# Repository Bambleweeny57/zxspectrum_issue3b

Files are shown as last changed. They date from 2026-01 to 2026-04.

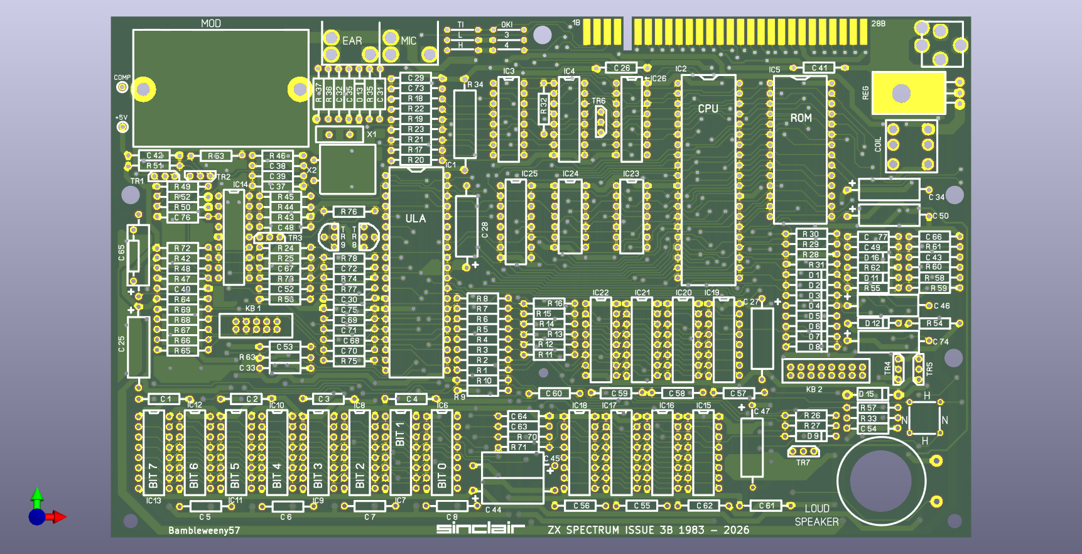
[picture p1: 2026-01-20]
images/issue3b.png

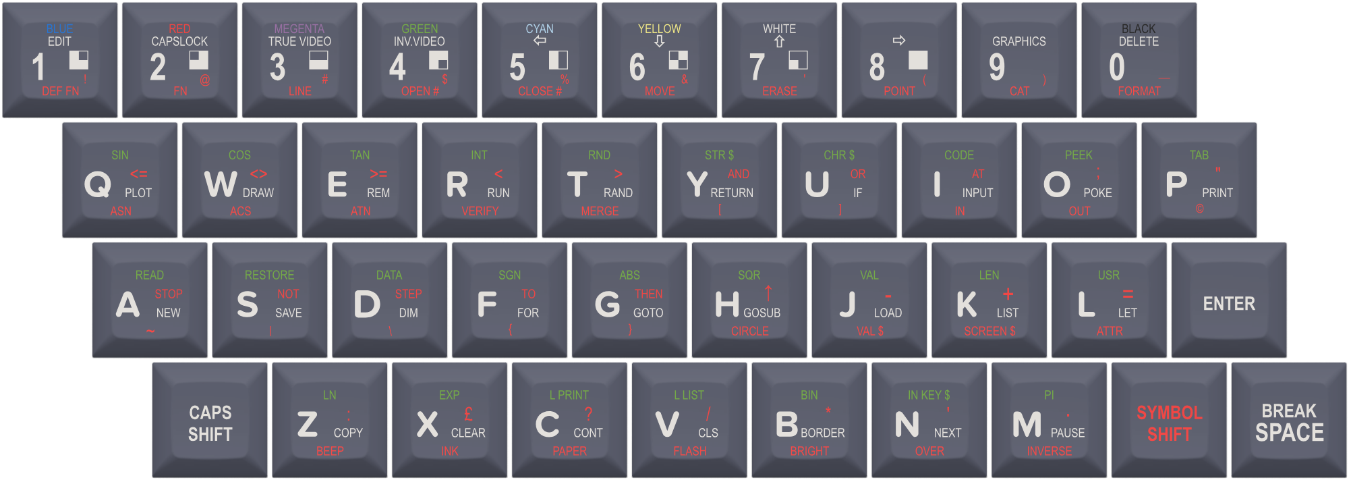
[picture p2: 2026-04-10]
images/ZXSpectrum-Keycaps.png

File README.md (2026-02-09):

# **ZX Spectrum Issue 3B — KiCad Reconstruction**

A faithful KiCad recreation of the **Sinclair ZX Spectrum Issue 3B motherboard**, reconstructed from original Gerber data and fully validated through multiple successful builds.  
This project preserves the 3B layout in an editable, open format and includes several companion PCBs designed to modernise, repair, or enhance the original Spectrum hardware.

---

## 🧭 Project Purpose

The aim of this repository is to provide a clean, accurate, and reproducible version of the Issue 3B board for:

- Restoring original machines  
- Building new units from scratch  
- Hardware experimentation and modding  
- Long‑term preservation of Sinclair’s design  

All PCBs included here have been **physically manufactured and tested**.

---

## 🛠️ Included PCBs

### **✔️ Issue 3B Motherboard (KiCad Reconstruction)**  
A complete KiCad recreation of the original Issue 3B board.

- Rebuilt directly from Gerbers  
- Trace‑accurate routing  
- Multiple boards assembled and working perfectly  
- Compatible with original components and modern equivalents  

---

### **✔️ Coil Replacement PCB**  
A compact, reliable drop‑in replacement for the original Spectrum coil assembly.

- Tested and working  
- More consistent output than ageing originals  
- Builder‑friendly footprint and assembly  

---

### **✔️ Composite Mod PCB (Internal Modulator Replacement)**  
This PCB is designed to **fit inside the original RF modulator can**, replacing the internal circuitry while keeping the metal can for authenticity.

- Produces a clean composite video output  
- Eliminates RF noise and modulator‑related issues  
- Fully validated on real hardware  
- Ideal for restorations where the external appearance should remain original  

---

### **✔️ Composite Modulator Replacement PCB**  
A full PCB replacement for the RF modulator can itself.

- Suitable for new builds or heavily damaged modulators  
- Provides modern composite output in a clean, serviceable form  
- Tested and working  

---

## 🧩 Issue 3B Schematic (Work in Progress)

A full schematic for the **Issue 3B motherboard** is currently being drafted.  
It lives in the main **`/src`** directory alongside the KiCad PCB project and is already far enough along to be useful for reference, verification, and troubleshooting.

- Based on the reconstructed PCB  
- Continuously refined as traces and nets are validated  
- Intended to become a complete, accurate representation of the 3B circuitry  
- A PDF export is also included in **`/images`** for quick viewing

This schematic will evolve as the project progresses, but it is already a solid and reliable companion to the board reconstruction.

---

## 📁 Repository Structure

| Path | Description |
|---|---|
| `/src` | KiCad project files for the Issue 3B board |
| `/zx_coil` | Coil replacement PCB |
| `/zx_composite_mod` | Composite mod PCB (internal modulator replacement) |
| `/zx_composite_modulator` | Full modulator replacement PCB |
| `README.md` | Project overview |

---

## 🔧 Build Status

All PCBs in this repository have been **successfully manufactured, assembled, and tested**.

| PCB | Status |
|-----|---|
| Issue 3B Motherboard | ✅ Working |
| Coil Replacement PCB | ✅ Working |
| Composite Mod PCB | ✅ Working |
| Composite Modulator PCB | ✅ Working |

---

## 📐 About the Issue 3B Revision

The Issue 3B is one of the later 48K Spectrum board revisions, featuring:

- Improved manufacturing consistency  
- Minor routing and grounding refinements  
- Updated power regulation layout  
- Compatibility with both early and late ULAs  

This reconstruction preserves the original routing and component placement as closely as possible.

---

## 🤝 Contributing

Contributions that improve accuracy, documentation, or long‑term preservation of the Issue 3B are welcome.  
This includes:

- Verified corrections to the schematic or PCB reconstruction  
- High‑resolution board scans, trace photos, or component placement references  
- Improvements to KiCad symbols, footprints, or net annotations  
- Build reports, troubleshooting notes, or compatibility findings  
- Additional companion PCBs that relate to the 3B ecosystem  

Please open an issue or pull request with clear details so changes can be reviewed and validated against real hardware where possible.

---

## 📜 License

This project is released for educational, preservation, and hobbyist use.  
You are free to study, modify, and build from the files provided.

The original Sinclair ZX Spectrum design remains the intellectual property of its respective rights holders.  
Please respect the historical significance of the original hardware.

---

## 🚀 How to Use This Project

### **Open in KiCad**
```bash
git clone https://github.com/Bambleweeny57/zxspectrum_issue3b

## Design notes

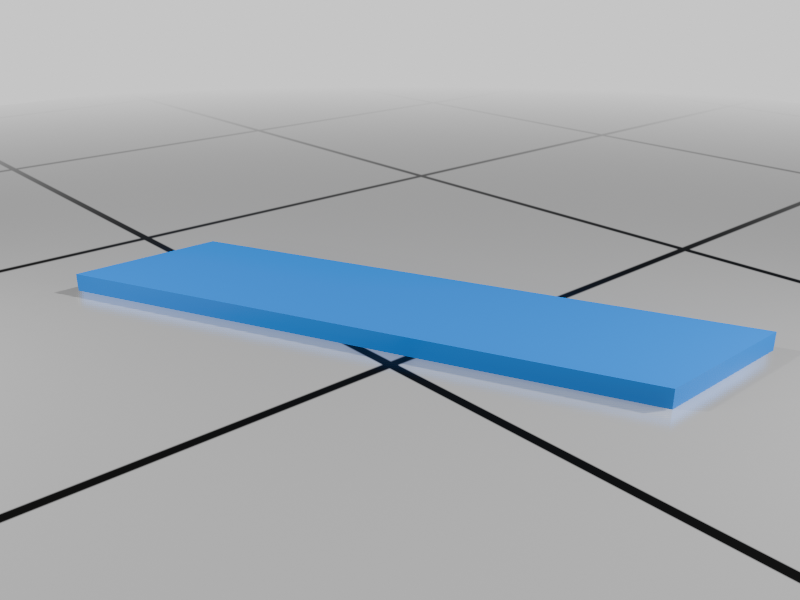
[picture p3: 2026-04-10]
case/Spectrum stripes files/images/rainbowsticker_green.png

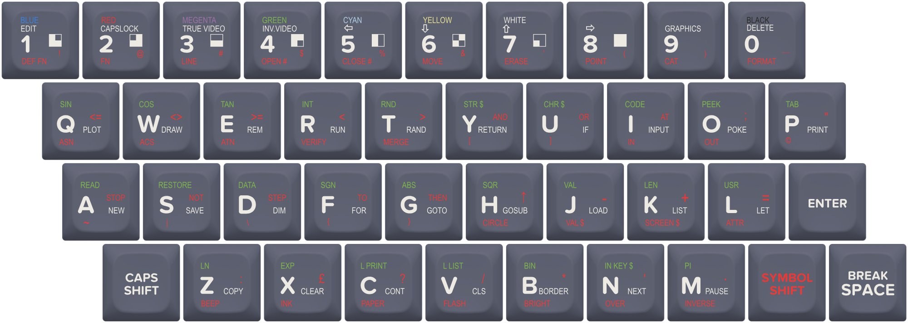
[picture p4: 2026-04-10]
keyboard/images/ZXSpectrum-Base.png

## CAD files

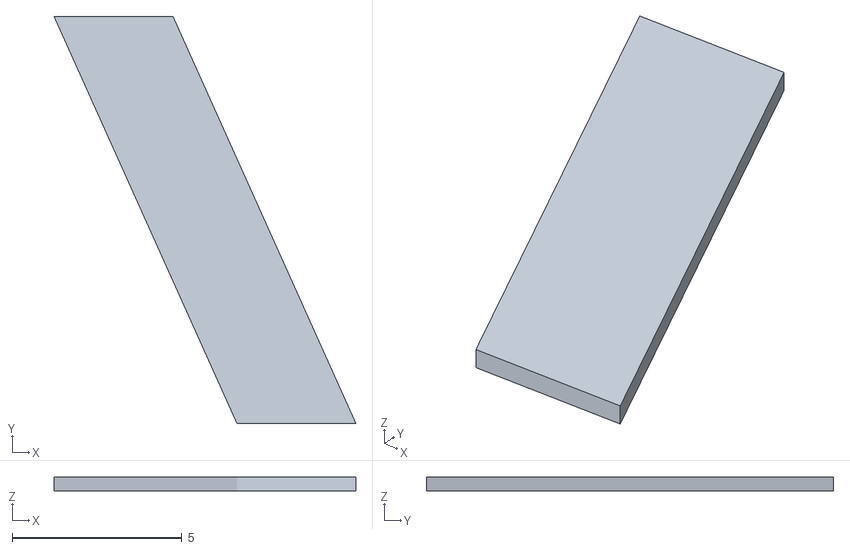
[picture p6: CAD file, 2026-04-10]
case/Spectrum stripes files/rainbowsticker_blue.stl
8.90 x 12.0 x 0.4

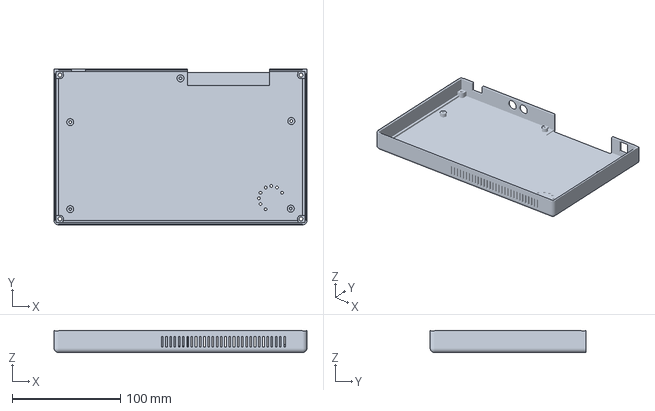
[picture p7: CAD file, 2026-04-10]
case/zxkb_bottom_curve_v0.1.3mf
234.0 x 144.0 x 20.4 mm

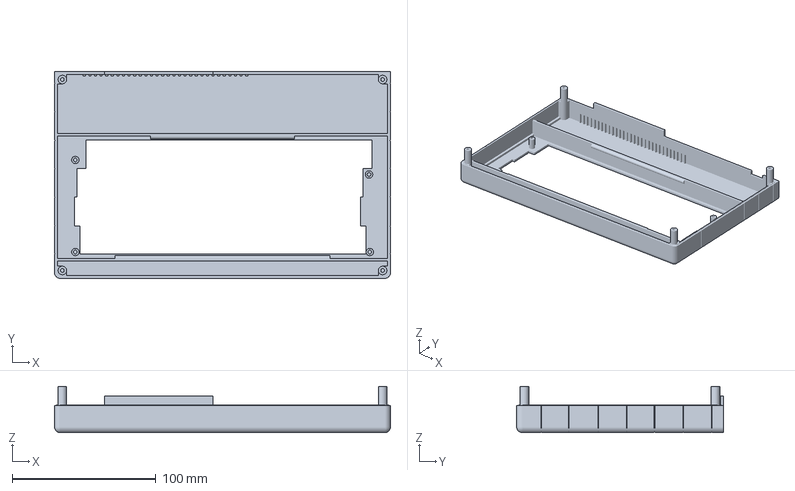
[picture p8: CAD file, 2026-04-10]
case/top case with logo - stripes.FCStd
234.0 x 144.0 x 32.2 mm
zxkb_top_curve_v0.3
zxkb_top_curve_v0.1_logo
rainbowsticker_blue
rainbowsticker_green
rainbowsticker_red
rainbowsticker_yellow

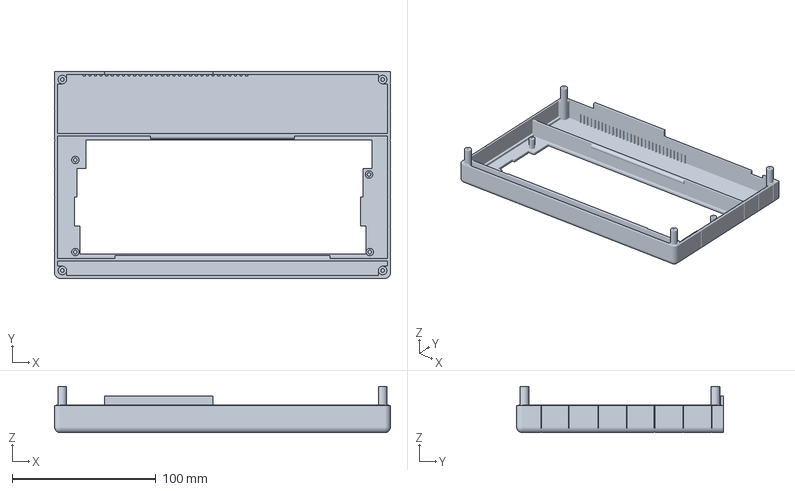
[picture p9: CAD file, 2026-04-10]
case/zxkb_top_curve_v0.3.3mf
234.0 x 144.0 x 32.2 mm

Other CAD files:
case/Spectrum stripes files/rainbowsticker_yellow.stl
case/joined-zxkb_top_curve_v0.1_logo.step
case/Spectrum stripes files/rainbowsticker_green.stl
case/Spectrum stripes files/rainbowsticker_red.stl
case/top case with logo.FCStd
case/joined-zxkb_top_curve_v0.1_logo.3mf
case/top case with logo - stripes.3mf
case/top case with logo.3mf
case/zxkb_bottom_curve_v0.1.stl
case/zxkb_top_curve_v0.3.stl

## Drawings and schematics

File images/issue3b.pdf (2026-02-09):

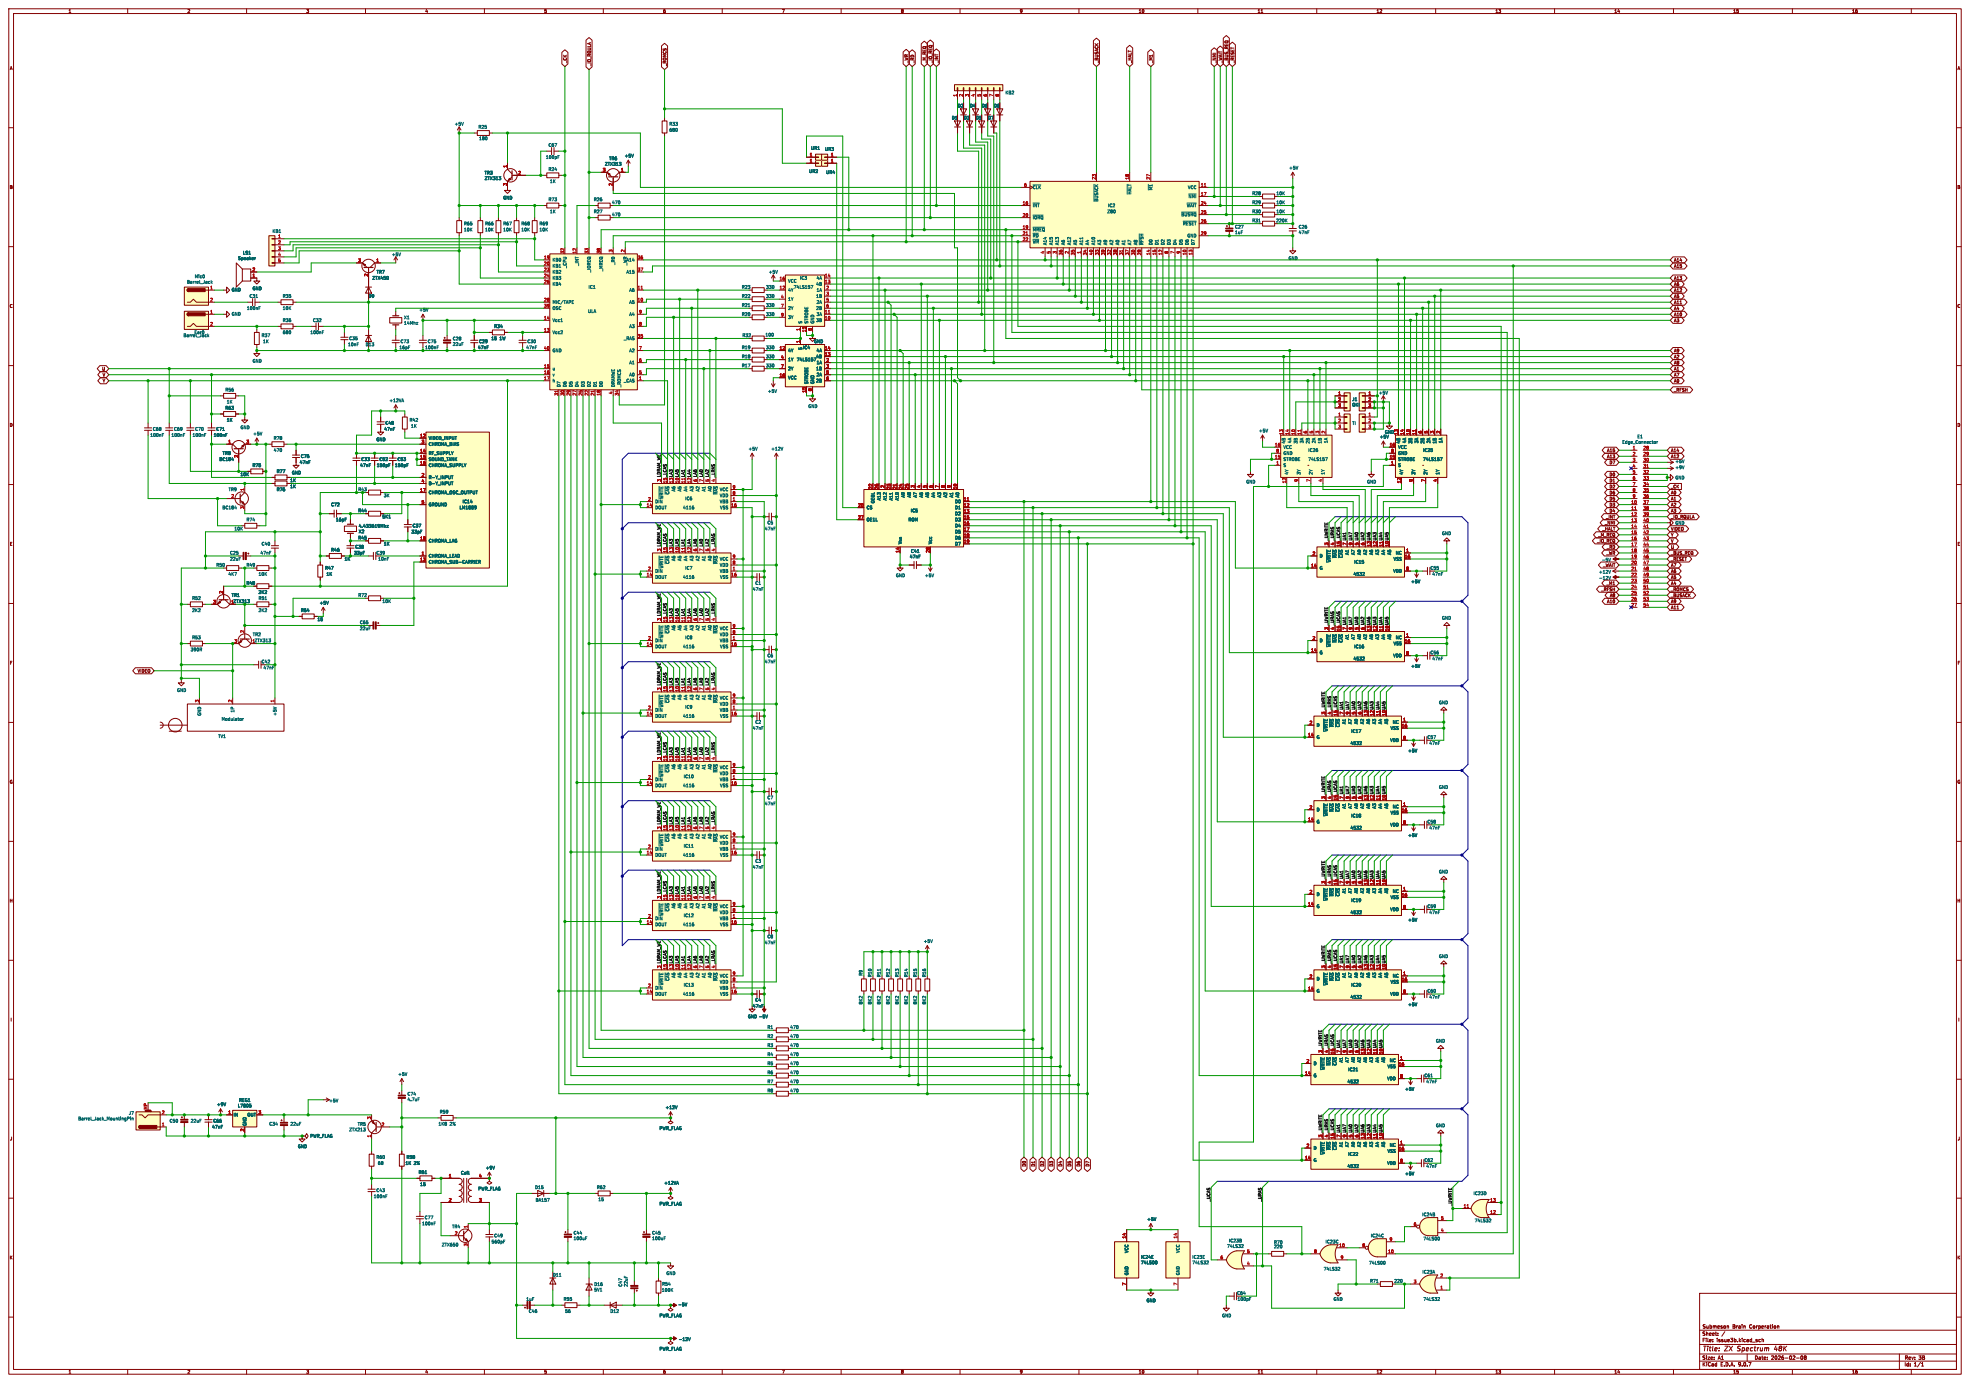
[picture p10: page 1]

11 ~{NMI}17 ~{WAIT}24 ~{BUSRQ}25 ~{RESET}26 GND

Id: 1/1 Title: ZX Spectrum 48K

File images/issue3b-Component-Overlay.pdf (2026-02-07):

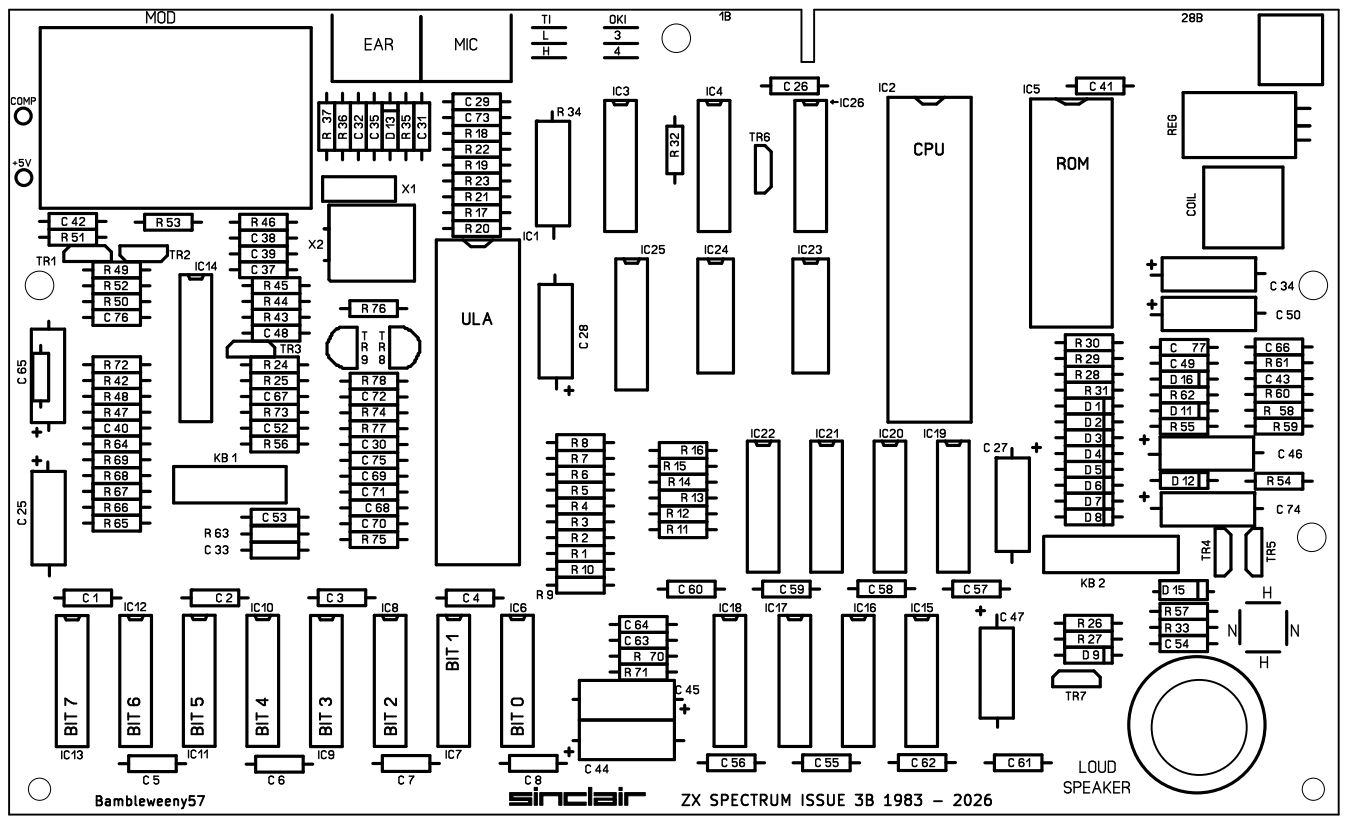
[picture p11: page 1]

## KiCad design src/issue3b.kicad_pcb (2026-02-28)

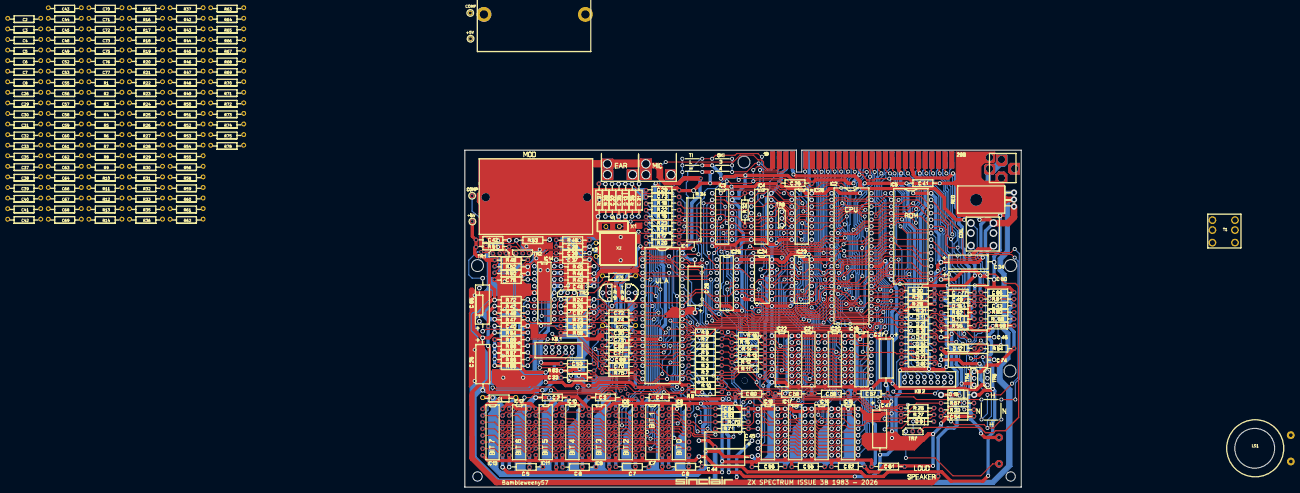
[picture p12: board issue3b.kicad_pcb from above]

Board: 2 copper layers, 126 parts (0 on the bottom side), 45 nets.

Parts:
C1, C2, C3, C4, C5, C6, C7, C8, C26, C29, C30, C33, C40, C41, C42, C48, C55, C56, C57, C58, C59, C60, C61, C62, C66, C76: 47nF; Passive
C31, C32, C43, C68, C69, C70, C71, C75, C77: 100nF; Passive
C35, C39: 10nF; Passive
C37, C38: 33pF; Passive
C44, C45: 100uF; Passive
C49: 560pF; Passive
C52, C53: 150pF; Passive
C63: 47pF; Passive
C64, C67: 100pF; Passive
C72, C73: 16pF; Passive
LS1: Speaker
R1, R2, R3, R4, R5, R6, R7, R8, R26, R27, R78: 470; Passive
R9, R10, R11, R12, R13, R14, R15, R16: 8k2; Passive
R17, R18, R19, R20, R21, R22, R23: 330; Passive
R24, R73: 1k; Passive
R25: 180; Passive
R28, R29, R30, R35, R49, R65, R66, R67, R68, R69, R72, R74, R75: 10K; Passive
R31: 220K; Passive
R32: 100; Passive
R33, R36: 680; Passive
R37, R42, R45, R46, R47, R56, R58, R63, R76, R77: 1K; Passive
R43: 3K; Passive
R44: 5K1; Passive
R48, R51, R52: 2K2; Passive
R50: 4K7; Passive
R53: 390R; Passive
R54: 100K; Passive
R55: 56; Passive
R59: 1K8; Passive
R60: 68R; Passive
R61, R62, R64: 15; Passive
R70, R71: 220; Passive
T1: Coil
TV1: Modulator
X1: 14Mhz; X1
X2: 4.43Mhz; X2

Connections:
+5V: C26.1, C29.2, C41.1, C55.2, C56.2, C57.2, C58.2, C59.2, C60.2, C61.2, C62.2, C75.2, R9.1, R10.1, R11.1, R12.1, R13.1, R14.1, R15.1, R16.1, R25.1, R28.1, R29.1, R30.1, R31.1, R64.2, R65.1, R66.1, R67.1, R68.1, R69.1, R73.1, R74.2, R75.2, R78.1
+9V: C66.2, T1.4 (SB)
+12V: C5.1, C6.1, C7.1, C8.1, C44.1, R59.2, R62.1
+12VA: C33.2, C45.1, C48.2, C52.2, C53.2, R42.1, R62.2
-5V: C1.1, C2.1, C3.1, C4.1, R54.1
-12VAC: C49.2, T1.3 (SA)
D0: R1.1, R9.2
D1: R2.1, R10.2
D2: R3.1, R11.2
D3: R4.1, R12.2
D4: R5.1, R13.2
D5: R6.1, R14.2
D6: R7.1, R15.2
D7: R8.1, R16.2
GND: C1.2, C2.2, C3.2, C4.2, C5.2, C6.2, C7.2, C8.2, C26.2, C29.1, C30.1, C33.1, C35.1, C37.2, C40.2, C41.2, C42.2, C43.1, C44.2, C45.2, C48.1, C49.1, C55.1, C56.1, C57.1, C58.1, C59.1, C60.1, C61.1, C62.1, C63.2, C64.2, C66.1, C72.2, C73.1, C75.1, C76.1, C77.1, LS1.1, R37.2, R43.1, R46.1, R47.1, R50.1, R52.1, R53.1, R54.2, R56.2, R58.2, R63.2, TV1.3 (GND)
unnamed: C31.1, R35.1
unnamed: C32.2, R36.2
unnamed: C38.1, C39.2, R46.2
unnamed: C38.2, R45.1, X2.2
unnamed: C43.2, R60.2, R61.1
unnamed: C63.1, R71.2
unnamed: C64.1, R70.2
unnamed: C72.1, R44.1, X2.1
unnamed: C73.2, X1.1
unnamed: C32.1, C35.2, R35.2
unnamed: R36.1, R37.1
unnamed: C52.1, R76.2
unnamed: C76.2, R78.2
unnamed: C37.1, R45.2
unnamed: R43.2, R44.2
unnamed: C53.1, R77.2
unnamed: C77.2, R61.2, T1.1 (AA)
unnamed: R48.1, R49.1, R50.2
unnamed: C40.1, C42.1, R49.2, R51.2, R64.1, R72.1, TV1.1 (+5V)
unnamed: C67.2, R24.1
unnamed: R58.1, R59.1
unnamed: C70.1, R75.1
unnamed: C71.1, R77.1
unnamed: C68.1, R74.1
unnamed: C69.1, R76.1
U: C69.2, R56.1
V: C71.2, R63.1
VIDEO: R53.2, TV1.2 (1P)
Y: C68.2, C70.2, R47.2, R48.2
_CK: C67.1, R24.2, R73.2

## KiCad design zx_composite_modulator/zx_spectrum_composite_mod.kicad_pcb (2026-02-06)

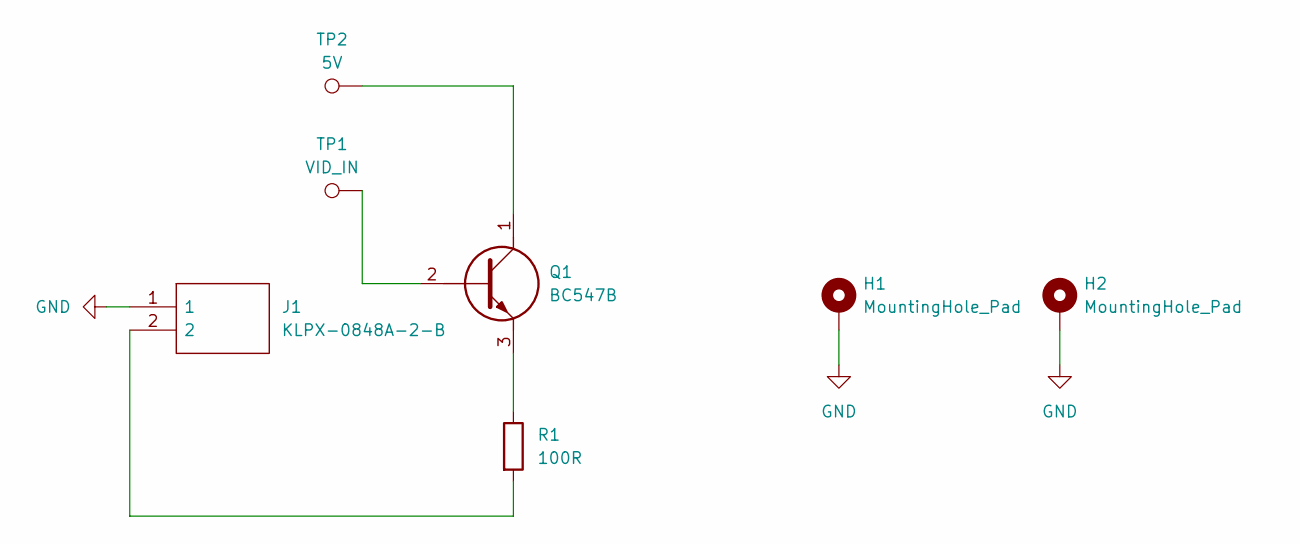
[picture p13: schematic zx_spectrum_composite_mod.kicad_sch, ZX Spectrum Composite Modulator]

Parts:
H1, H2: MountingHole_Pad; MountingHole_3.2mm_M3_Pad
J1: KLPX-0848A-2-B; KLPX0848A2B; Mouser Part Number 806-KLPX-0848A-2-B
Q1: BC547B; TO127P419X482X1041-3P; Mouser Part Number 512-BC547B
R1: 100R; R_Axial_DIN0207_L6.3mm_D2.5mm_P10.16mm_Horizontal
TP1: VID_IN; Pin_D0.7mm_L6.5mm_W1.8mm_FlatFork
TP2: 5V; Pin_D0.7mm_L6.5mm_W1.8mm_FlatFork

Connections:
GND: H1.1, H2.1, J1.1
unnamed: J1.2, R1.2
unnamed: Q1.1, TP2.1
unnamed: Q1.2, TP1.1
unnamed: Q1.3, R1.1

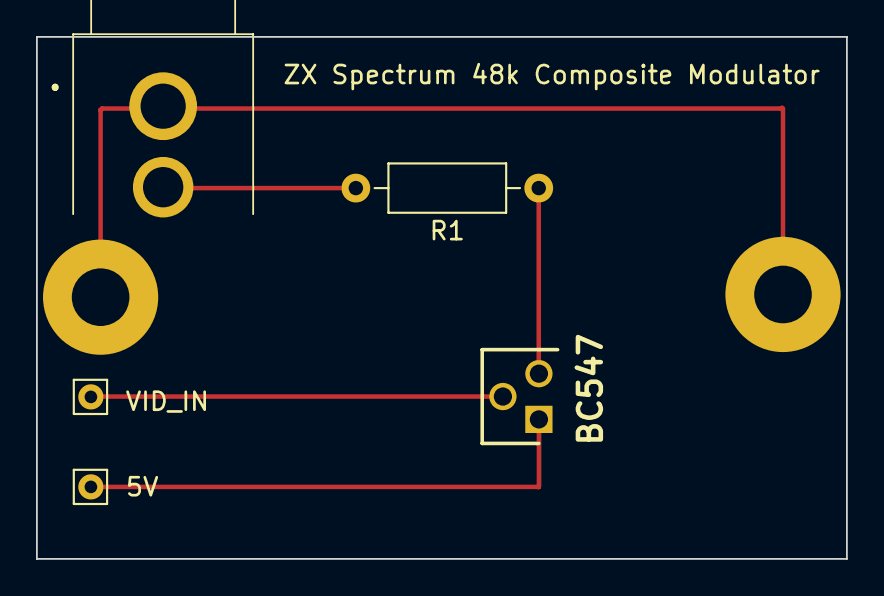
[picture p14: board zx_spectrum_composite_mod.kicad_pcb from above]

Board: 2 copper layers, 45.0 x 29.0 mm, 7 parts (0 on the bottom side), 5 nets.

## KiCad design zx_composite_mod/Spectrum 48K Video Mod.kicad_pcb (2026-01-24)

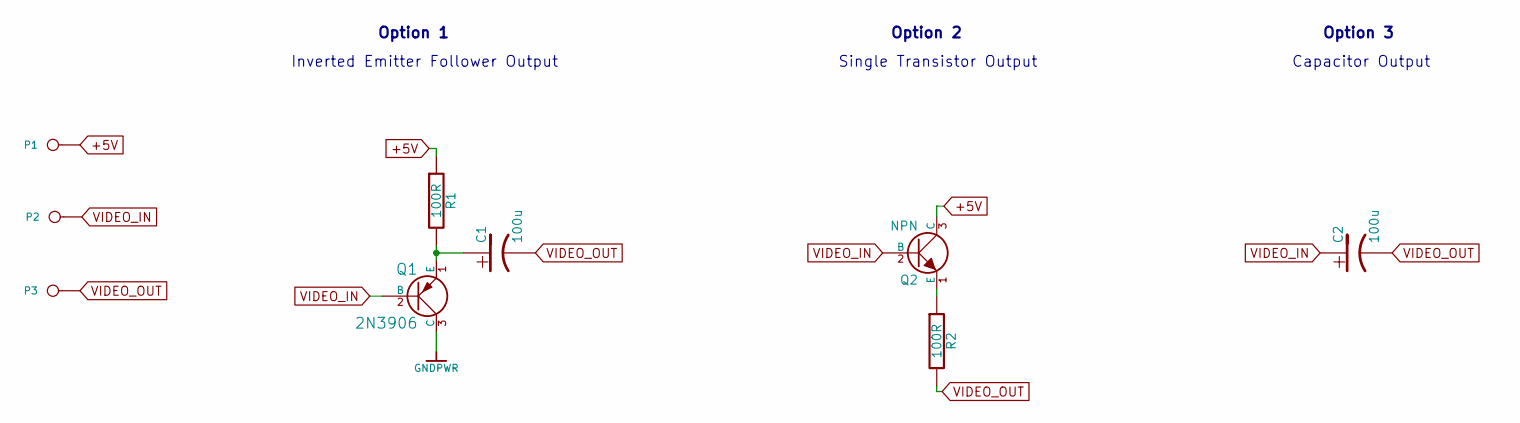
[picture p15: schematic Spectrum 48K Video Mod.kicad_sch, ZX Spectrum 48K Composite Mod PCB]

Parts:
C1, C2: 100u; CP_Radial_D7.5mm_P2.50mm
P1, P2, P3: CONN_1; Pin_Header_Straight_1x01_Pitch2.54mm
Q1: 2N3906; TO-92_Inline_Narrow_Oval
Q2: NPN; TO-92_Inline_Narrow_Oval
R1, R2: 100R; R_Axial_DIN0207_L6.3mm_D2.5mm_P10.16mm_Horizontal

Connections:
+5V: P1.1, Q2.3 (C), R1.1
GNDPWR: Q1.3 (C)
unnamed: C1.1, Q1.1 (E), R1.2
unnamed: Q2.1 (E), R2.1
VIDEO_IN: C2.1, P2.1, Q1.2 (B), Q2.2 (B)
VIDEO_OUT: C1.2, C2.2, P3.1, R2.2

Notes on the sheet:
Single Transistor Output
Option 1
Option 2
Option 3
Capacitor Output
Inverted Emitter Follower Output

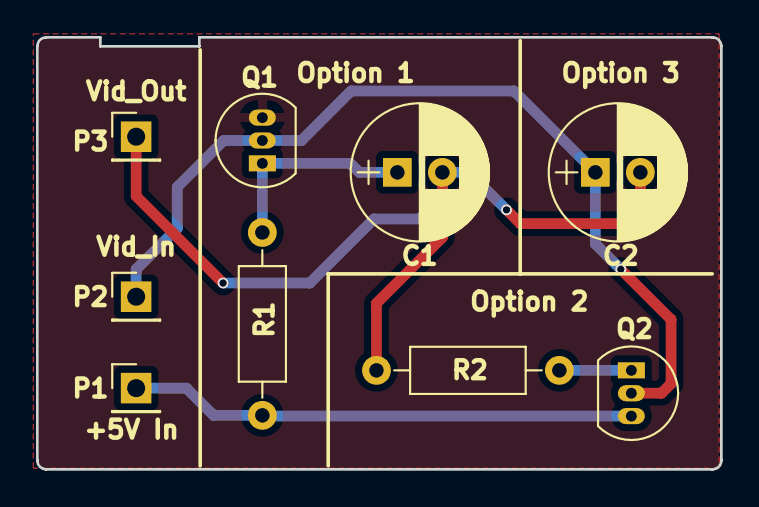
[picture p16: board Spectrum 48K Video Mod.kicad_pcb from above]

Board: 2 copper layers, 38.0 x 24.0 mm, 9 parts (0 on the bottom side), 5 nets.

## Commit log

2026-01-19 inital push
    [issue3b.kicad_pcb, issue3b.kicad_sch]
2026-01-19 change directory
    [issue3b.kicad_pcb, issue3b.kicad_sch]
2026-01-20 created gerbers
    [issue3b-B_Cu.gbr, issue3b-B_Mask.gbr, issue3b-B_Paste.gbr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]
2026-01-24 new gerbers
    [issue3b-B_Cu.gbr, issue3b-B_Mask.gbr, issue3b-B_Paste.gbr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]
2026-01-24 new gerbers for the coil
    [zx_coil-B_Cu.gbr, zx_coil-B_Mask.gbr, zx_coil-B_Paste.gbr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]
2026-01-24 added composite mod pcb and single transistor composite modulator replacement
    [Spectrum 48K Video Mod-B_Cu.gbl, Spectrum 48K Video Mod-B_Mask.gbs, Spectrum 48K Video Mod-B_Silkscreen.gbo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]
2026-02-06 reduced drill in coil
    [zx_coil-B_Cu.gbr, zx_coil-B_Mask.gbr, zx_coil-B_Paste.gbr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]
2026-02-07 Added an HTML BOM with Silkscreen.
2026-02-08 Added R25 to BOM Started Schematic
    [issue3b.kicad_sch, xissue3b.kicad_sch]
2026-02-08 Added Schematic PDF
    [issue3b.kicad_sch]
2026-02-09 Updated schematic re produced schematic pdf
    [issue3b.kicad_sch, xissue3b.kicad_sch]
2026-02-09 updated schematic
    [issue3b.kicad_sch]
2026-02-11 added some new footprints
    [issue3b.kicad_pcb, issue3b.kicad_sch, xissue3b.kicad_sch]
2026-02-11 fixed ibom location
    [xissue3b.kicad_sch]
2026-02-28 moved applied footprints
    [issue3b.kicad_pcb]
2026-04-10 keyboard added
    [joined-zxkb_top_curve_v0.1_logo.3mf, joined-zxkb_top_curve_v0.1_logo.step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]
